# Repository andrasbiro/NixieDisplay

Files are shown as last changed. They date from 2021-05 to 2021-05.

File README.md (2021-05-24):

# Nixie Display

This is my modular nixie display/clock.

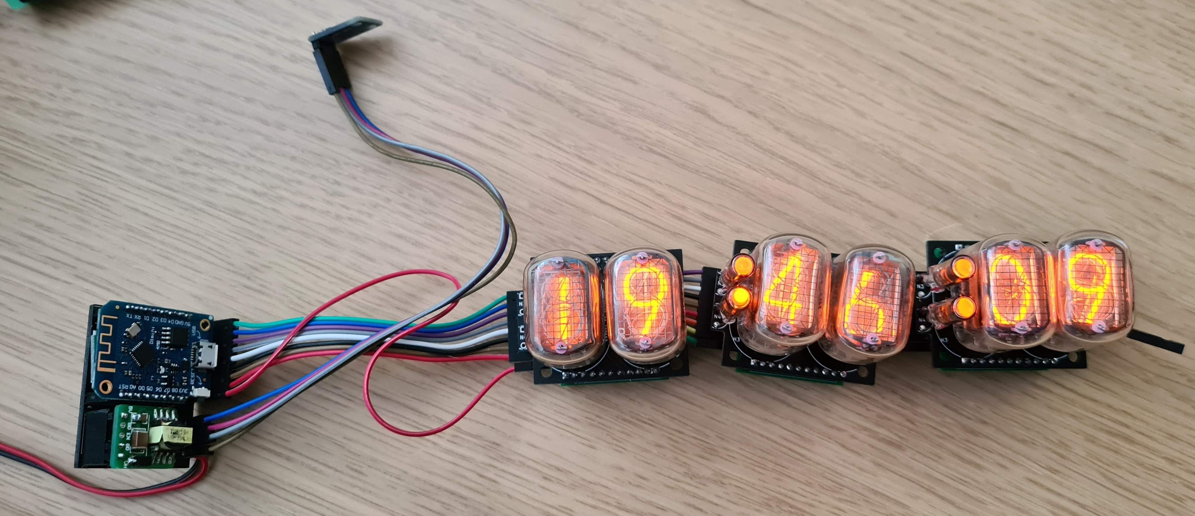
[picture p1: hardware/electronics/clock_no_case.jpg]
Bare clock before case design


It is designed around modules. Each module has:

- 2 nixie tube (with decimal point)
- preceiding colon
- shift register based cathode driver circuit
- any number of modules can be cascaded together

With my boards, the cathode drivers are sandwitched behind the main boards,

The control is based around a Wemos D1 mini and a small 170V power supply. It can also dim the tubes via PWM controlled optogate switching off the high voltage from the tubes.

The recommended input voltage is between 7.5V and 12V.

## Hardware

The PCB design is the most problematic part of the project. I'm proud of the small outline of the NixieBoards, but other than that, they are full with problems. For more details see [its own readme](./hardware/electronics/README.md).

3d printed case coming soon.

## Firmware

The firmware is written in platformIO.

### NixieLib

The nixie driver is written in its own library, what I called NixieLib, and is fully documented in its header file. It supports the following input formats:

- 2 digit number + 4 boolean for the 4 dots (decimal and colon) for each module
- Integer, right adjusted across all modules
- Fixed point number (float input, number of decimals in another input)

### Clock application

The clock gets the current time from NTP, converts it to local time (CET/CEST, modify the winter/summer variables for your timezone) and displays ont the tubes.

It also has OTA enabled and telnet based debugging.

## Future developement

These are the modifications I plan:

- 3d printed case
- simplify NTP/timezone, use ESP's time.h instead of libs
- MQTT support, so it can display anything from my home assistant
- BH1750fvi based dimming
- second display, using Z570M tubes

Otherwise, grab it and modify it to your heart's content, but I probably won't. Pull requests are welcome!

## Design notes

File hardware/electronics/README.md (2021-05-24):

# PCBs for nixie modules

These are the PCBs for the modular nixie display I designed, *but note that they
have many problems*. I'm a firmware engineer and I hate working on PCBs, and
even though these have many problems (and I autorouted most of them, which seems
sacrilege in hw design), it reached the point where it is good enough for me.

Pull requests are welcome.

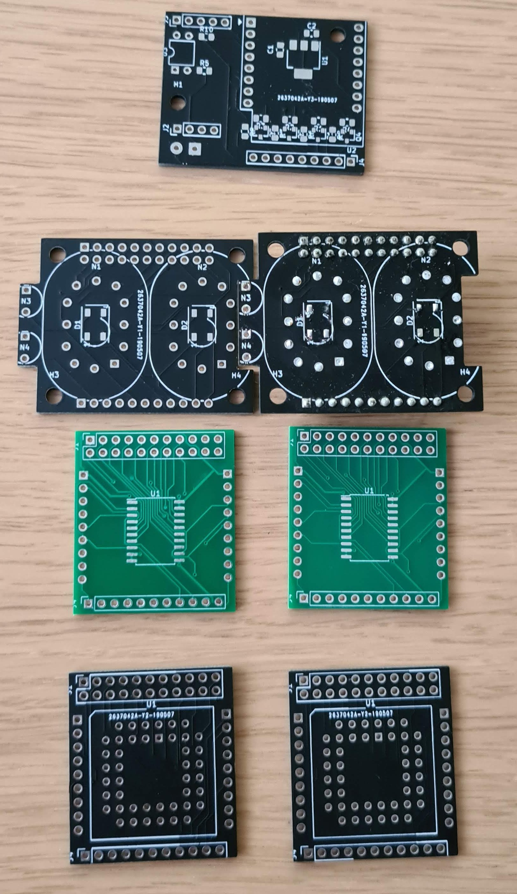
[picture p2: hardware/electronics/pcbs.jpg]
Bare PCBs


## The Nixie board

The Nixie board is designed around IN-12B nixies with INS-1 neon bulbs as colon.
When the colon is not populated, the pads of it can be hidden in the preceding
board. Therefor, the board can be used both as clock displays with a colon and
numerical displays.

It will likely work with thin legged standing style tubes too (like the GDR,
like Z570M).

This board also has 4 M3 mounting holes, in each corner (on a 36.5x29mm
rectangle)

The anode resistors should be tuned for the tubes and anode voltage, here's what
I used for IN-12B / INS-1 at 170V power supply:

- R1/R3: 12kOhm (main anode resistor)
- R2/R4: 91kOhm (additional resistor on the decimal point's cathode)
- R5/R6: 240kOhm (INS-1 anode resistor)

### Known issues

- The board includes a WS2812B ("neopixel") backlight for each tube but that
  never worked. However, I never really wanted to use it, just thought about
  maybe if it looks good, so I won't fix it.
- When used with TPIC6592 drivers, INS-1 needs an extra ~50V zener in series to
  allow it turn off. Since it is not socketed, it can be easily added.

## The Driver boards

The driver board fits under the nixie board and provides power/control to it. I
have two versions of it:

- Based on HV5122 (in socket)
- Based on TPIC6592 (smd)

I highliy recommend the one based on TPIC6592, as HV5122 does not have a true
latch (only output enable) and way more expensive.

Both design has footprint for filter caps, but I never used it on the TPIC
design.

The module connecting pin headers are ~15mm from each other when the nixie board
is used without colon, but I ended up using wires on one side and 90 degree pin
headers on the other. The excess wire can be tugged away between the boards.

### Known issues

- The 15mm distance was designed for pin headers measured for 14mm distance, but
  what I got in the end was much closer
- The HV5122 board is not very well tested. It was an earlier iteration of the
  design, but with a few hw errors, I managed to blew my chips, and I don't
  intend to order new ones.

## The Control board

**The control board has the most issues, and I strongly recommend against
manufacturing it before fixing it. However, I did fix it with ugly hacks, so I
won't bother paying for another run. I put it here for archiving only.**

The control board is designed around a Wemos D1 mini (or clone) and a
cheap/small 170V power supply, both readily available from aliexpress and
similar sites. It also has a pin header for I2C, where I have a bh1750fvi light
sensor panel connected for dimming.

### Known issues

- I missed routing the 12V input to anything - fixable with a jumper wire
- AMS1117 was a bad decision for running the Wemos, and every other 5V device. I
  currently have a 3 pin DCDC board wired to its pads
- I used an optogate for dimming (via PWM) the high voltage. My driver board has
  a shutdown pin that would have probably work just as good
- The level shifters are configured for 12V (HV5122), and needs cutting a
  trace/adding a jumper wire to set it for 5V, needed for the TPIC drivers
- The power input needs bigger holes on the PCB to be able to use with proper
  wire gauge.

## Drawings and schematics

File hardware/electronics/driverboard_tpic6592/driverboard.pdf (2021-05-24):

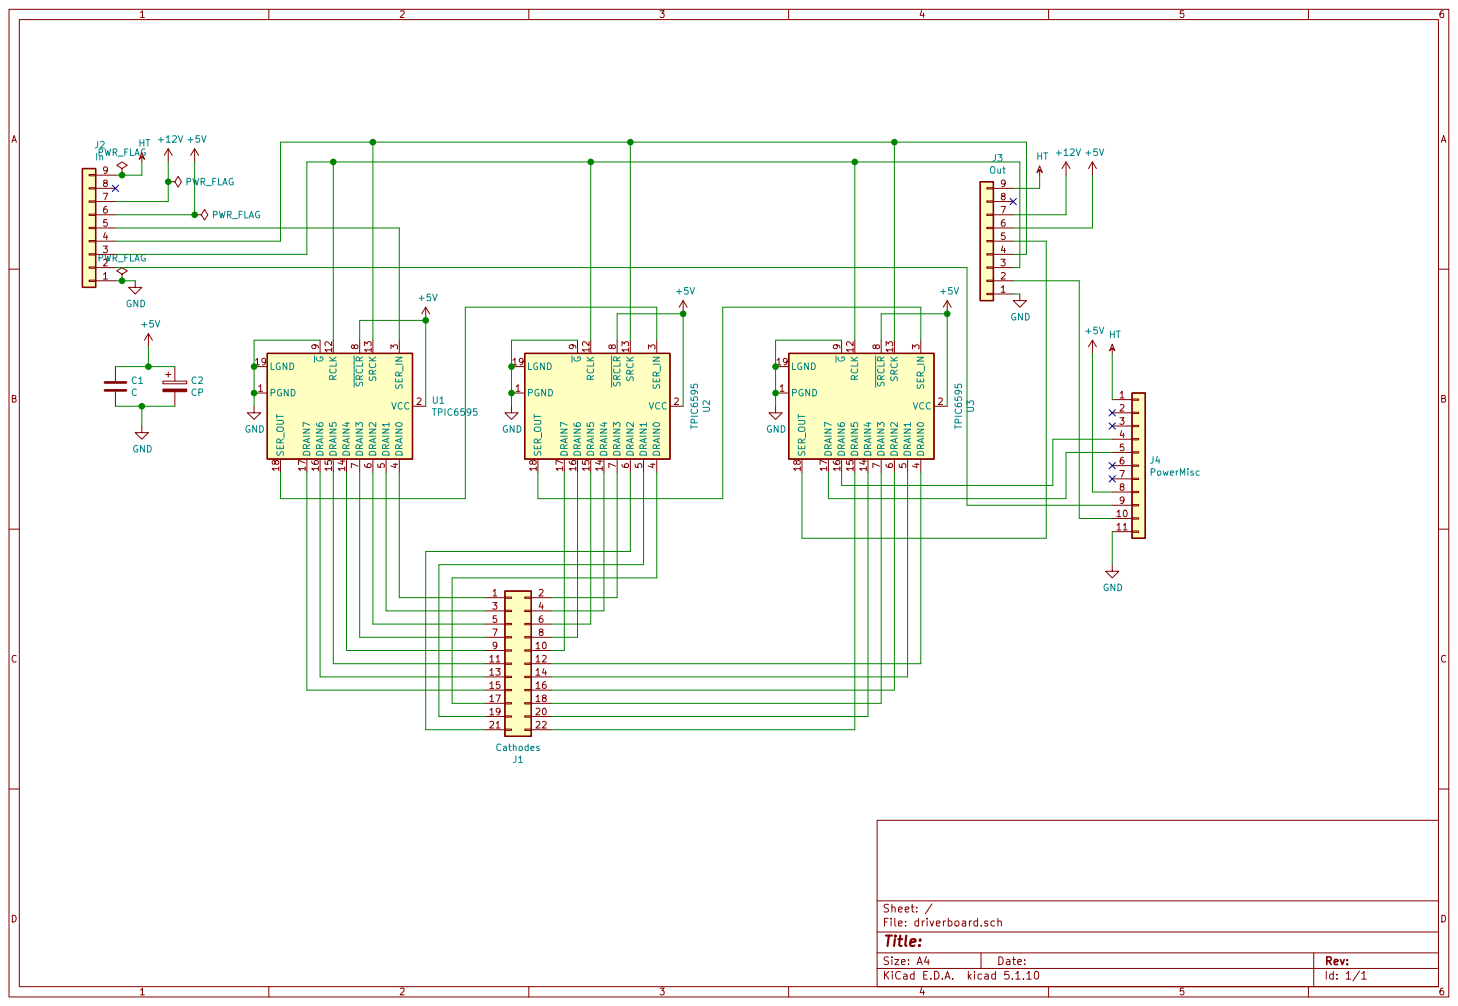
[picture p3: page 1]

Id: 1/1 Title: File: driverboard.sch Sheet: / GND

9 | 10
11 | 12
13 | 14
15 | 16
17 | 18

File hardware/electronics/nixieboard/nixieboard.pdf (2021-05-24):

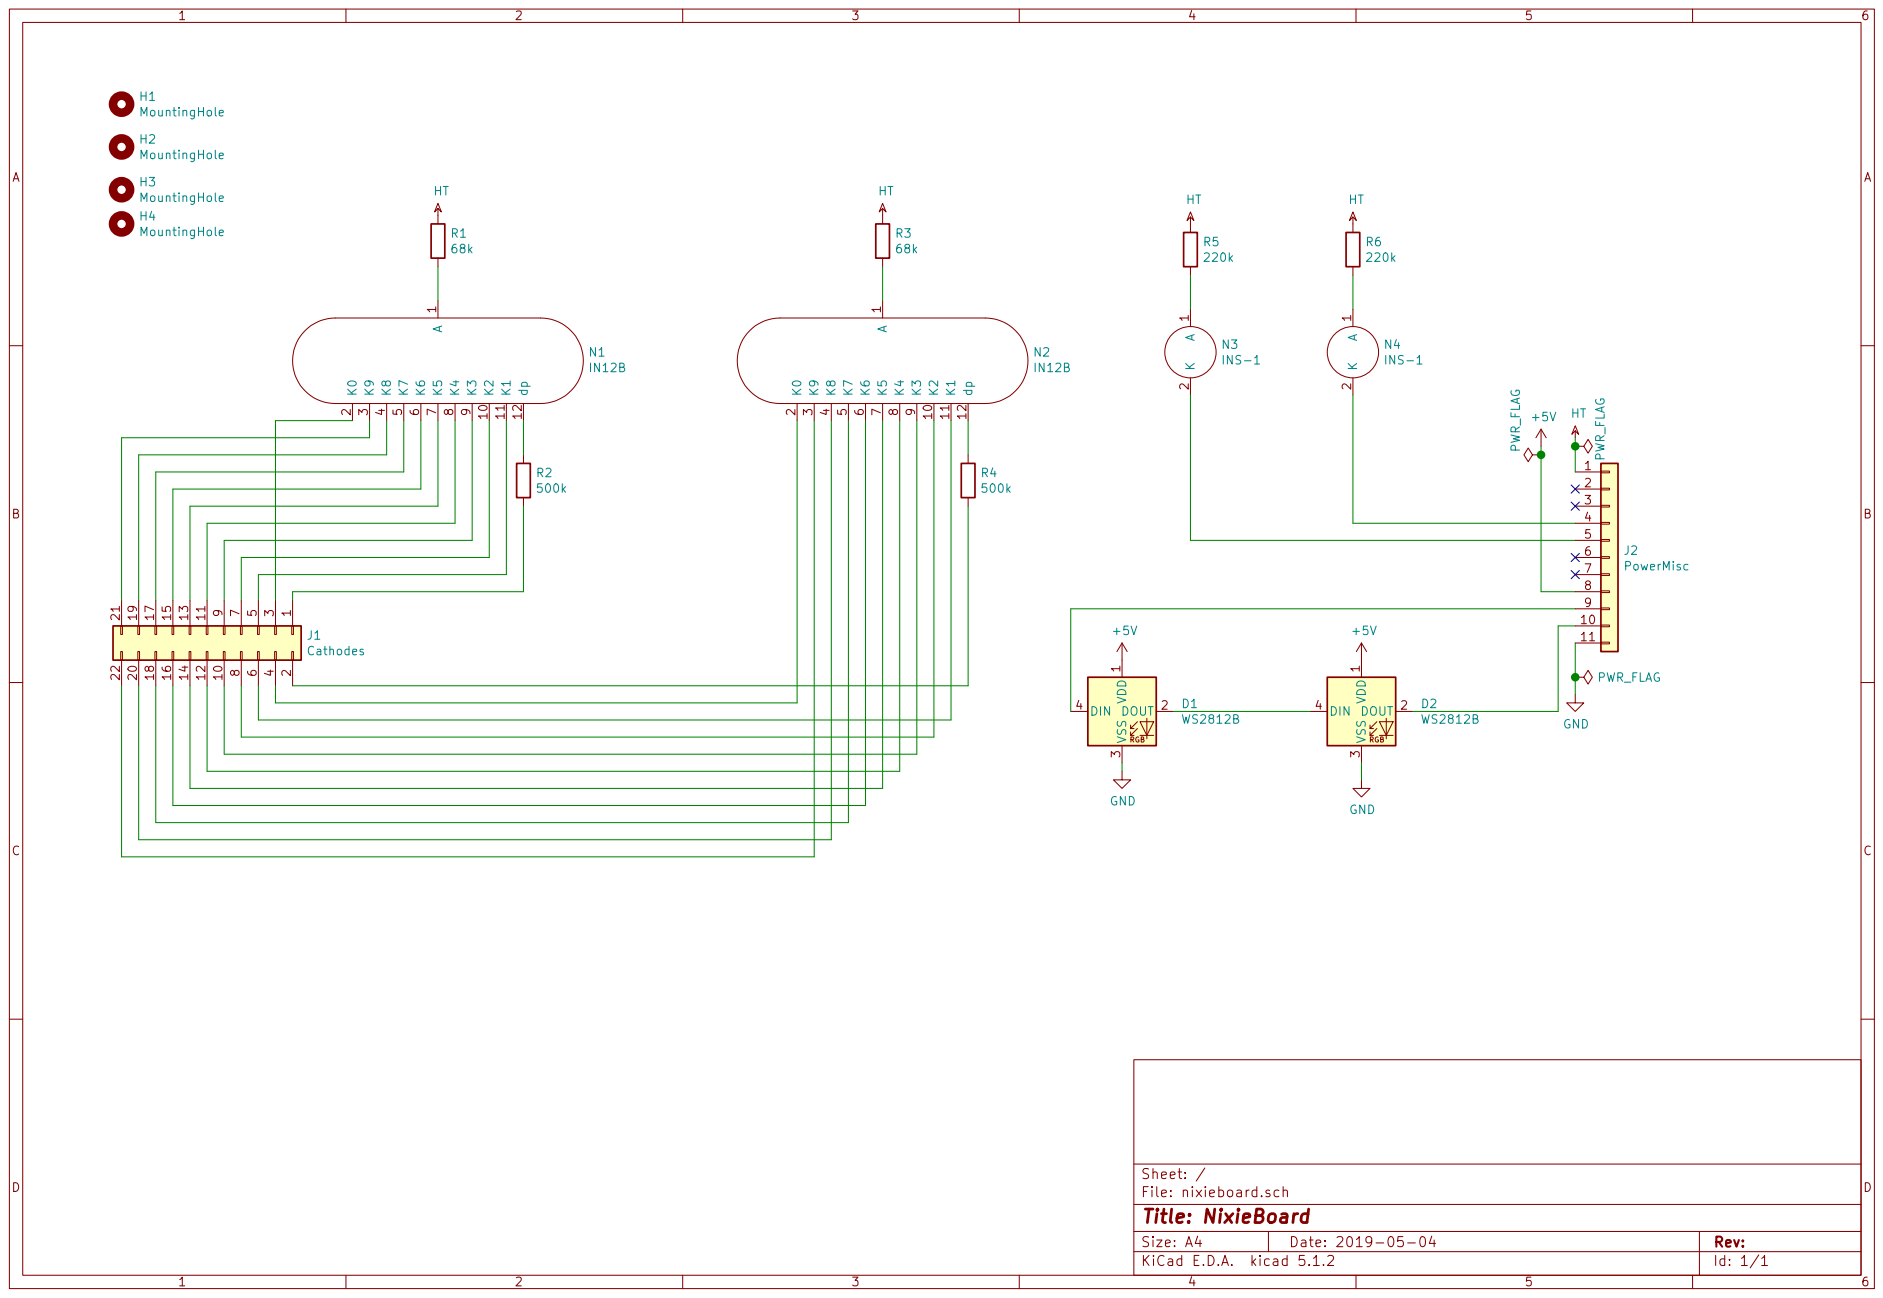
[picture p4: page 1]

3 DIN 4 D1WS2812B HT HT GND GND

File: nixieboard.sch Sheet: /
Id: 1/1 Title: NixieBoard

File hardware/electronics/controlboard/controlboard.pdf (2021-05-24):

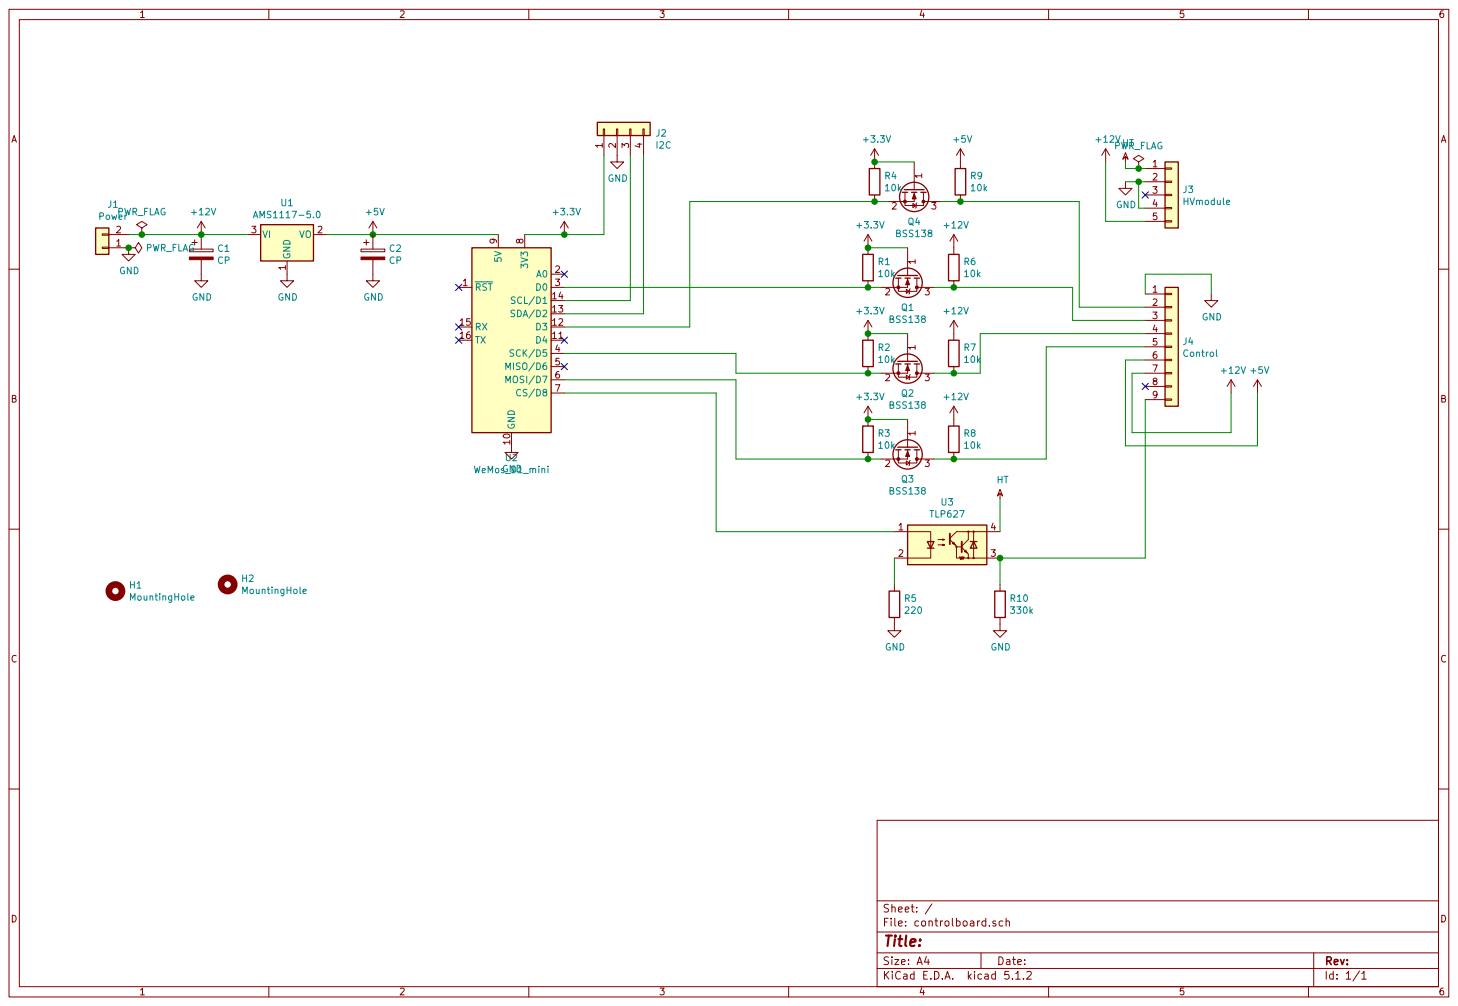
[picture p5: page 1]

Id: 1/1 Title: File: controlboard.sch Sheet: /

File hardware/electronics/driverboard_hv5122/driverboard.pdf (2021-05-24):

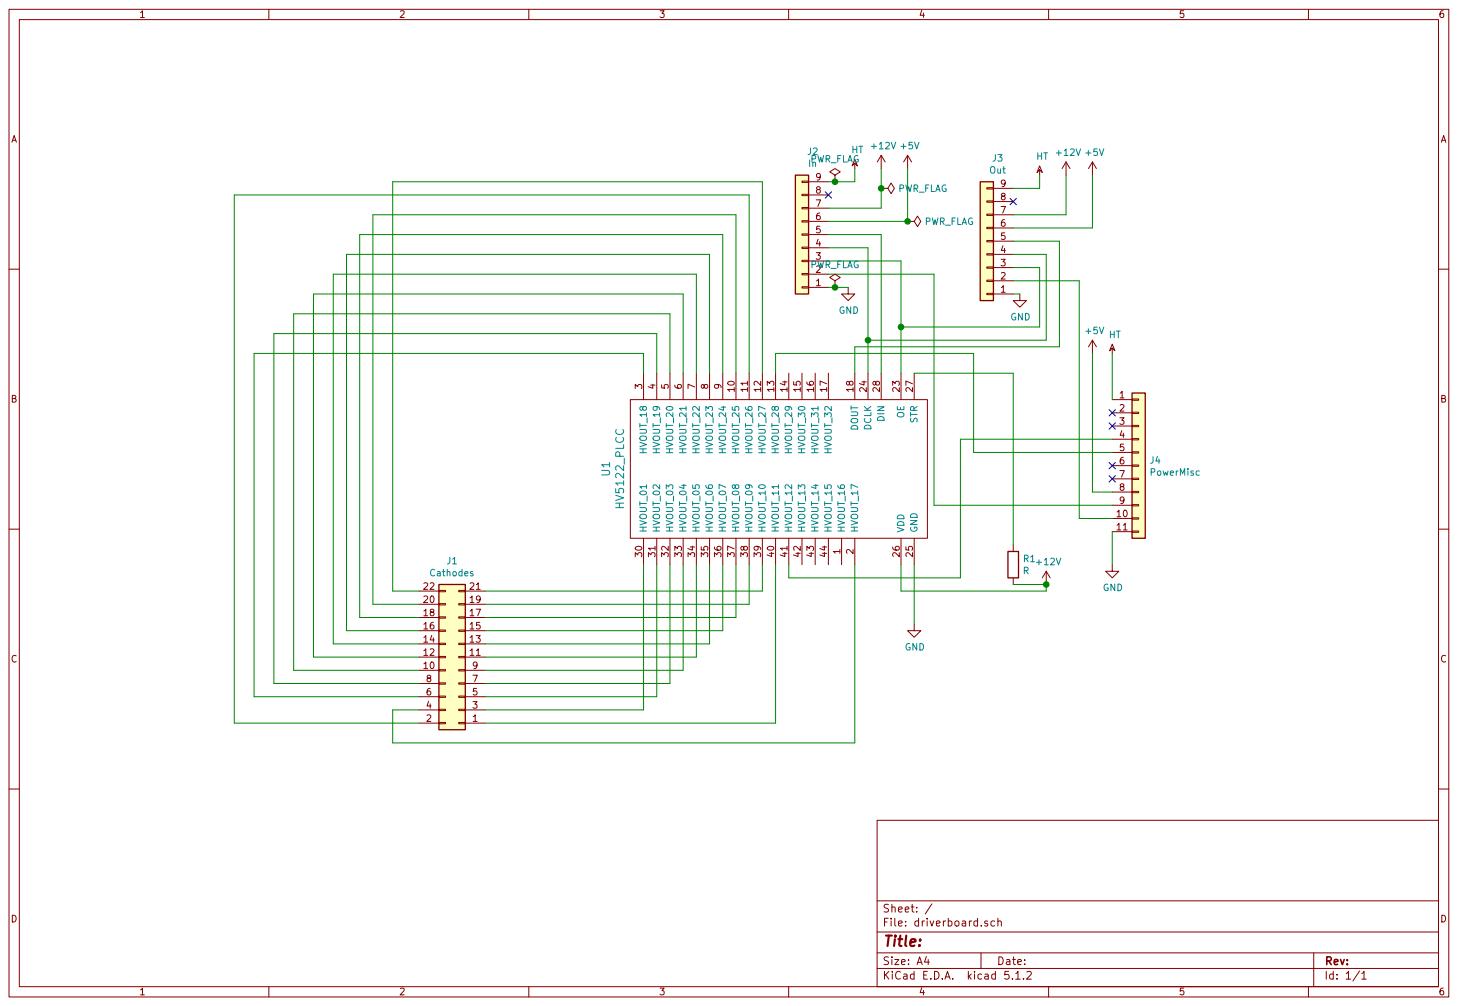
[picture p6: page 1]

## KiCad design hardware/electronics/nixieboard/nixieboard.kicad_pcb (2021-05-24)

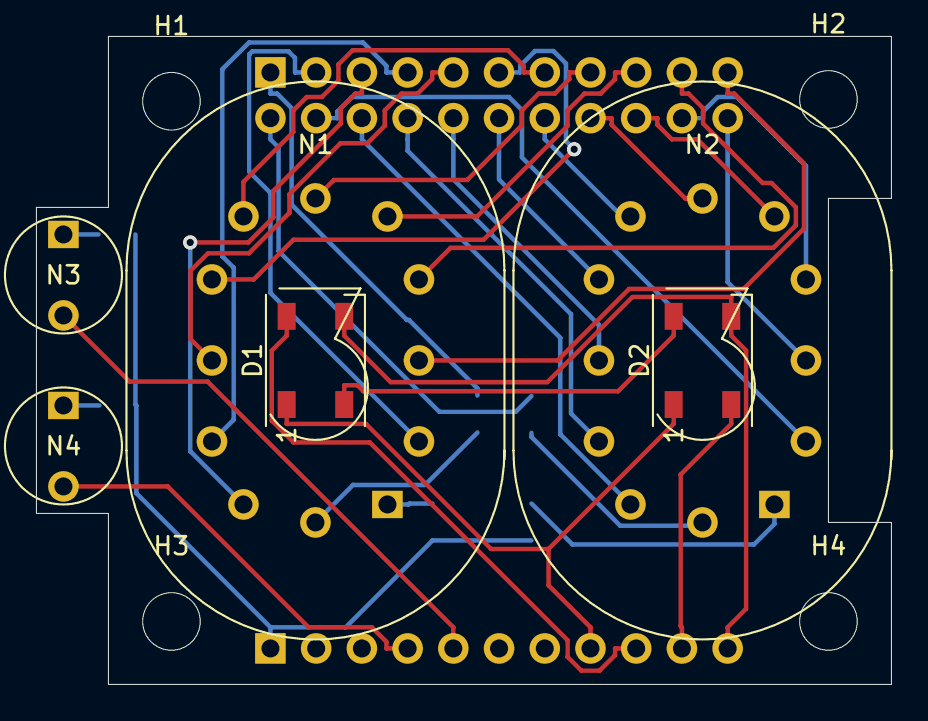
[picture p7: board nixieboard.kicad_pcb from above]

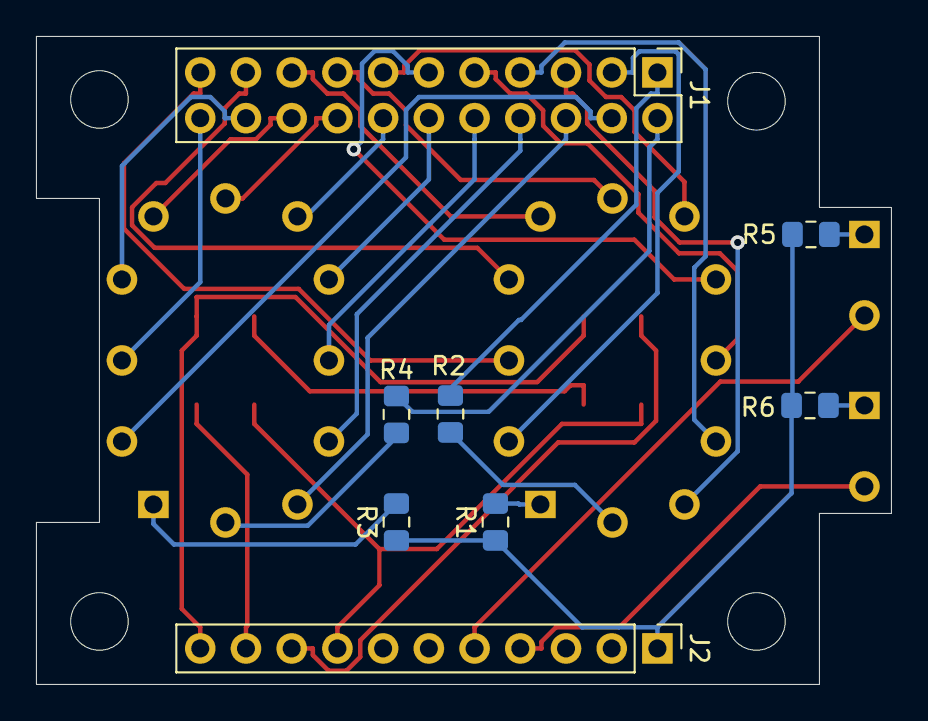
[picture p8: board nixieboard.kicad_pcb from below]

Board: 2 copper layers, 47.5 x 36.0 mm, 18 parts (8 on the bottom side), 36 nets.

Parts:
D1, D2: WS2812B; LED_WS2812B_PLCC4_5.0x5.0mm_P3.2mm
H1, H2, H3, H4: MountingHole; MountingHole_3.2mm_M3
J1: Cathodes; PinHeader_2x11_P2.54mm_Vertical
J2: PowerMisc; PinHeader_1x11_P2.54mm_Vertical
N1, N2: IN12B; in12b_pinsocket
N3, N4: INS-1; ins-1
R1, R3: 68k; R_0805_2012Metric_Pad1.15x1.40mm_HandSolder
R2, R4: 500k; R_0805_2012Metric_Pad1.15x1.40mm_HandSolder
R5, R6: 220k; R_0805_2012Metric_Pad1.15x1.40mm_HandSolder

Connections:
+5V: D1.1, D2.1, J2.8
GND: D1.3, D2.3, J2.11
HT: J2.1, R1.1, R3.1, R5.1, R6.1
unnamed: D1.2, D2.4
unnamed: D1.4, J2.9
unnamed: D2.2, J2.10
unnamed: J1.1, R2.2
unnamed: J1.2, R4.2
unnamed: J1.3, N1.2
unnamed: J1.4, N2.2
unnamed: J1.5, N1.11
unnamed: J1.6, N2.11
unnamed: J1.7, N1.10
unnamed: J1.8, N2.10
unnamed: J1.9, N1.9
unnamed: J1.10, N2.9
unnamed: J1.11, N1.8
unnamed: J1.12, N2.8
unnamed: J1.13, N1.7
unnamed: J1.14, N2.7
unnamed: J1.15, N1.6
unnamed: J1.16, N2.6
unnamed: J1.17, N1.5
unnamed: J1.18, N2.5
unnamed: J1.19, N1.4
unnamed: J1.20, N2.4
unnamed: J1.21, N1.3
unnamed: J1.22, N2.3
unnamed: J2.4, N4.2
unnamed: J2.5, N3.2
unnamed: N1.1, R1.2
unnamed: N1.12, R2.1
unnamed: N2.1, R3.2
unnamed: N2.12, R4.1
unnamed: N3.1, R5.2
unnamed: N4.1, R6.2

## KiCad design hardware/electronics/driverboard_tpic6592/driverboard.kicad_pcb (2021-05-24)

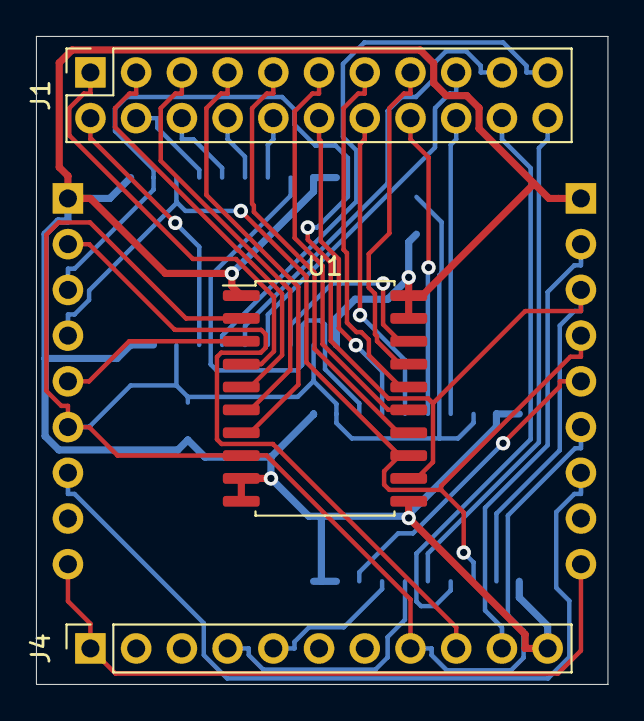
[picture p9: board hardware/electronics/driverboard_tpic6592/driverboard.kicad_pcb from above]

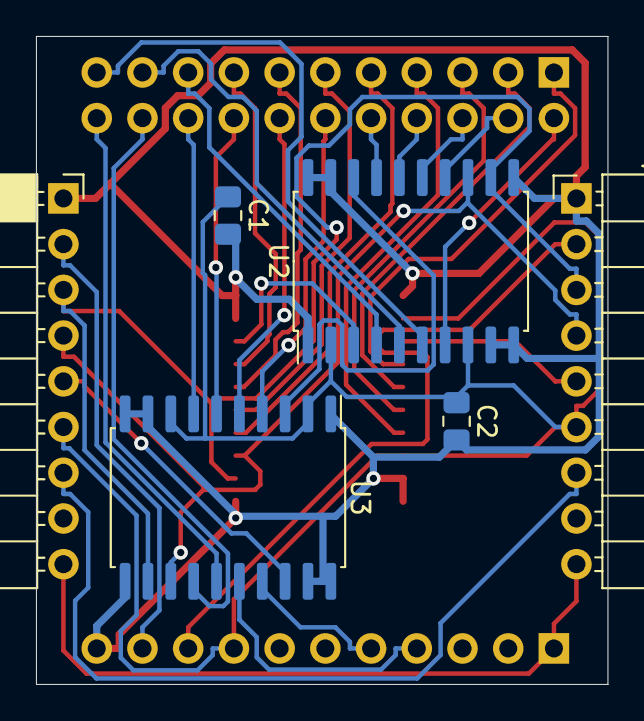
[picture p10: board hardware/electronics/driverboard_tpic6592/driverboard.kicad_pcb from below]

Board: 2 copper layers, 31.8 x 36.0 mm, 9 parts (6 on the bottom side), 36 nets.

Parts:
C1: C; C_0805_2012Metric_Pad1.18x1.45mm_HandSolder
C2: CP; C_0805_2012Metric_Pad1.18x1.45mm_HandSolder
J1: Cathodes; PinSocket_2x11_P2.54mm_Vertical
J2: In; PinHeader_1x09_P2.54mm_Horizontal
J3: Out; PinSocket_1x09_P2.54mm_Horizontal
J4: PowerMisc; PinSocket_1x11_P2.54mm_Vertical
U1, U2, U3: TPIC6595; SOIC-20W_7.5x12.8mm_P1.27mm

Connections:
+5V: C1.1, C2.1, J2.6, J3.6, J4.8, U1.2, U1.8, U2.2, U2.8, U3.2, U3.8
+12V: J2.7, J3.7
GND: C1.2, C2.2, J2.1, J3.1, J4.11, U1.1, U1.9, U1.10, U1.11, U1.19, U1.20, U2.1, U2.9, U2.10, U2.11, U2.19, U2.20, U3.1, U3.9, U3.10, U3.11, U3.19, U3.20
HT: J2.9, J3.9, J4.1
unnamed: J1.1, U1.4
unnamed: J1.2, U2.7
unnamed: J1.3, U1.5
unnamed: J1.4, U2.14
unnamed: J1.5, U1.6
unnamed: J1.6, U2.15
unnamed: J1.7, U1.7
unnamed: J1.8, U2.16
unnamed: J1.9, U1.14
unnamed: J1.10, U2.17
unnamed: J1.11, U1.15
unnamed: J1.12, U3.4
unnamed: J1.13, U1.16
unnamed: J1.14, U3.5
unnamed: J1.15, U1.17
unnamed: J1.16, U3.6
unnamed: J1.17, U2.4
unnamed: J1.18, U3.7
unnamed: J1.19, U2.5
unnamed: J1.20, U3.14
unnamed: J1.21, U2.6
unnamed: J1.22, U3.15
unnamed: J2.2, J4.9
unnamed: J2.3, J3.3, U1.12, U2.12, U3.12
unnamed: J2.4, J3.4, U1.13, U2.13, U3.13
unnamed: J2.5, U1.3
unnamed: J3.2, J4.10
unnamed: J3.5, U3.18
unnamed: J4.4, U3.16
unnamed: J4.5, U3.17
unnamed: U1.18, U2.3
unnamed: U2.18, U3.3

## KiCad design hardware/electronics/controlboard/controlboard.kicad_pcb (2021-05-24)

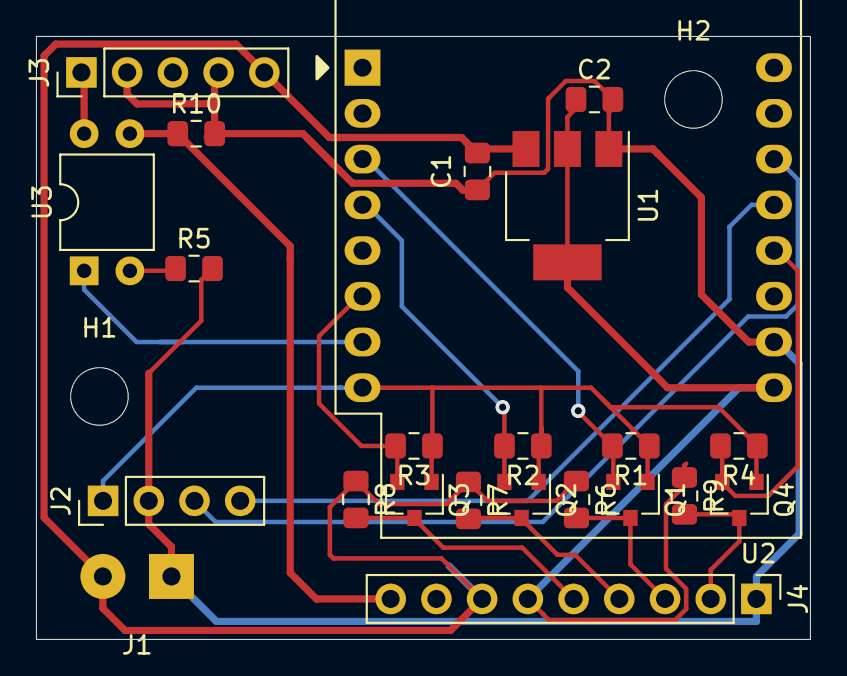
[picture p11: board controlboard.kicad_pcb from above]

Board: 2 copper layers, 43.0 x 33.5 mm, 25 parts (0 on the bottom side), 18 nets.

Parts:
C1, C2: CP; C_0805_2012Metric_Pad1.15x1.40mm_HandSolder
H1, H2: MountingHole; MountingHole_3.2mm_M3_DIN965
J1: Power; SolderWirePad_1x02_P3.81mm_Drill1mm
J2: I2C; PinHeader_1x04_P2.54mm_Vertical
J3: HVmodule; PinHeader_1x05_P2.54mm_Vertical
J4: Control; PinHeader_1x09_P2.54mm_Vertical
Q1, Q2, Q3, Q4: BSS138; SOT-23
R1, R2, R3, R4, R6, R7, R8, R9: 10k; R_0805_2012Metric_Pad1.15x1.40mm_HandSolder
R5: 220; R_0805_2012Metric_Pad1.15x1.40mm_HandSolder
R10: 330k; R_0805_2012Metric_Pad1.15x1.40mm_HandSolder
U1: AMS1117-5.0; SOT-223-3_TabPin2
U2: WeMos_D1_mini; WEMOS_D1_mini_light
U3: TLP627; DIP-4_W7.62mm

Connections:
+3V3: J2.1, Q1.1, Q2.1, Q3.1, Q4.1, R1.1, R2.1, R3.1, R4.1, U2.8
+5V: C2.1, J4.6, R9.1, U1.2, U2.9
+12V: C1.1, J1.2, J3.5, J4.7, R6.1, R7.1, R8.1, U1.3
GND: C1.2, C2.2, J1.1, J2.2, J3.2, J3.4, J4.1, R5.2, R10.2, U1.1, U2.10
HT: J3.1, U3.4
unnamed: J2.3, U2.14
unnamed: J2.4, U2.13
unnamed: J4.2, Q4.3, R9.2
unnamed: J4.3, Q1.3, R6.2
unnamed: J4.4, Q2.3, R7.2
unnamed: J4.5, Q3.3, R8.2
unnamed: J4.9, R10.1, U3.3
unnamed: Q1.2, R1.2, U2.3
unnamed: Q2.2, R2.2, U2.4
unnamed: Q3.2, R3.2, U2.6
unnamed: Q4.2, R4.2, U2.12
unnamed: R5.1, U3.2
unnamed: U2.7, U3.1

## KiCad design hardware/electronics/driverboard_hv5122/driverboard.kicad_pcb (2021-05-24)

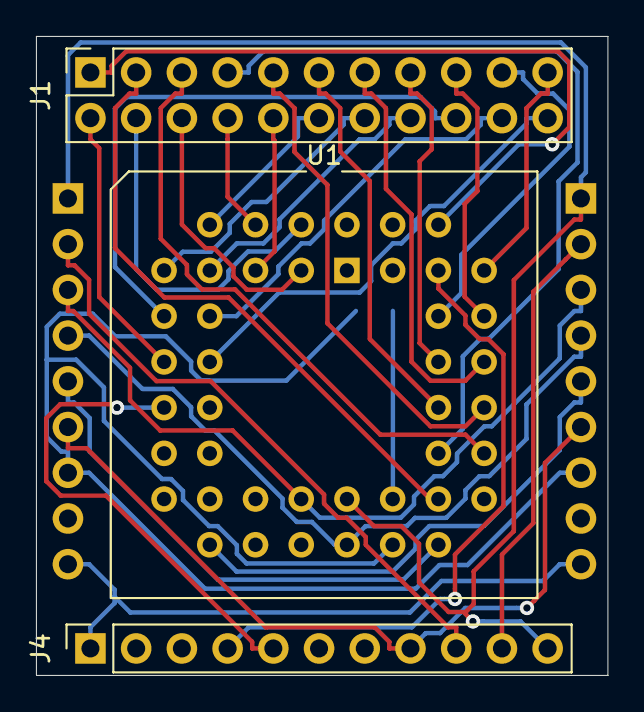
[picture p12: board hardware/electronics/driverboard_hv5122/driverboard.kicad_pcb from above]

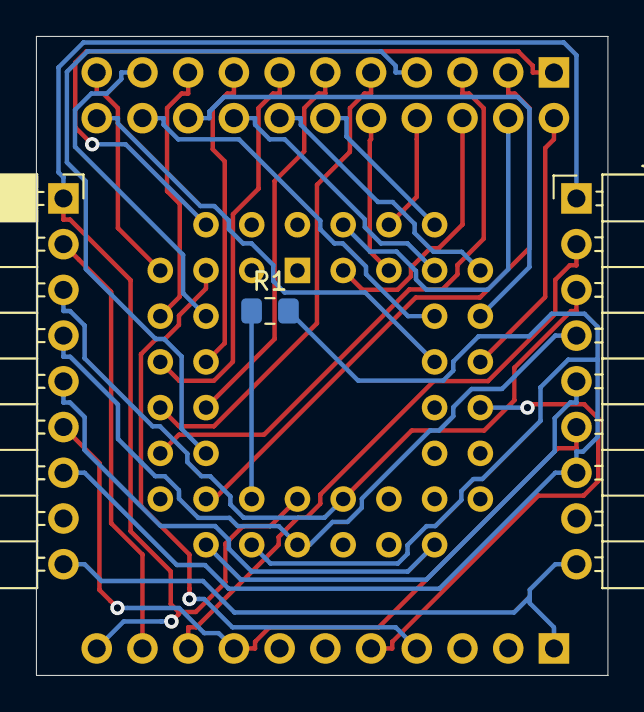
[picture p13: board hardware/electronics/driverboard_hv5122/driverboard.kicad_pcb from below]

Board: 2 copper layers, 31.8 x 35.5 mm, 6 parts (3 on the bottom side), 35 nets.

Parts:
J1: Cathodes; PinSocket_2x11_P2.54mm_Vertical
J2: In; PinHeader_1x09_P2.54mm_Horizontal
J3: Out; PinSocket_1x09_P2.54mm_Horizontal
J4: PowerMisc; PinSocket_1x11_P2.54mm_Vertical
R1: R; R_0805_2012Metric_Pad1.15x1.40mm_HandSolder
U1: HV5122_PLCC; PLCC-44_THT-Socket

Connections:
+5V: J2.6, J3.6, J4.8
+12V: J2.7, J3.7, R1.2, U1.26
GND: J2.1, J3.1, J4.11, U1.25
HT: J2.9, J3.9, J4.1
unnamed: J1.1, U1.40
unnamed: J1.2, U1.11
unnamed: J1.3, U1.30
unnamed: J1.4, U1.2
unnamed: J1.5, U1.31
unnamed: J1.6, U1.3
unnamed: J1.7, U1.32
unnamed: J1.8, U1.4
unnamed: J1.9, U1.33
unnamed: J1.10, U1.5
unnamed: J1.11, U1.34
unnamed: J1.12, U1.6
unnamed: J1.13, U1.35
unnamed: J1.14, U1.7
unnamed: J1.15, U1.36
unnamed: J1.16, U1.8
unnamed: J1.17, U1.37
unnamed: J1.18, U1.9
unnamed: J1.19, U1.38
unnamed: J1.20, U1.10
unnamed: J1.21, U1.39
unnamed: J1.22, U1.12
unnamed: J2.2, J4.9
unnamed: J2.3, J3.3, U1.23
unnamed: J2.4, J3.4, U1.24
unnamed: J2.5, U1.28
unnamed: J3.2, J4.10
unnamed: J3.5, U1.18
unnamed: J4.4, U1.41
unnamed: J4.5, U1.13
unnamed: R1.1, U1.27

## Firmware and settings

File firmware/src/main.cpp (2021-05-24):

#include <ESP8266WiFi.h>

#include <ESP8266WebServer.h>
#include <WiFiManager.h>
#include <ArduinoOTA.h>

#include <NTPClient.h>
#include <WiFiUdp.h>
#include <TimeLib.h>
#include <Timezone.h>

#include <Adafruit_NeoPixel.h>

#include "NixieLib.h"

#define GPIO_LATCH D0
#define GPIO_PWM D8

#define GPIO_MOSI D7
#define GPIO_SCK D5

#define GPIO_NEOPIXEL D3

//D1 SCL, D2 SDA

#define NAME "Nixie ESP Clock"

WiFiUDP ntpUDP;
NTPClient timeClient(ntpUDP);
WiFiManager wifiManager;

WiFiServer telnetServer(23);
WiFiClient debugClient;

Stream *debug = &Serial;

TimeChangeRule winter = {"CET", Last, Sun, Oct, 2, 60};    //UTC + 1 hours
TimeChangeRule summer = {"CEST", Last, Sun, Mar, 2, 120};     //UTC + 2 hours
Timezone timeZone(winter, summer);

#define NUMMODULES 3
NixieLib nixies = NixieLib(NUMMODULES, NIXIE_MODULE_TYPE_TPIC6592, GPIO_LATCH, GPIO_PWM, 0);

Adafruit_NeoPixel leds = Adafruit_NeoPixel(NUMMODULES*2, GPIO_NEOPIXEL, NEO_GRB + NEO_KHZ800);


void setup() {
  Serial.begin(115200);


  nixies.setBrightness(PWMRANGE); //5 is practical minimum

  //blank tubes, but light all the dots
  nixies.setNixieModule(0, 00, BLANKBOTHDIGITS, true, true, true, true);
  nixies.setNixieModule(1, 00, BLANKBOTHDIGITS, true, true, true, true);
  nixies.setNixieModule(2, 00, BLANKBOTHDIGITS, true, true, true, true);
  nixies.updateNixies();

  //The LEDs do not work, except sometimes the first one. So turn it off for uniformity
  leds.begin();
  leds.fill(0);
  leds.show();

  wifiManager.autoConnect("AutoConnectAP"); //TODO this is blocking. Add RTC and non-blocking config
  timeClient.begin();
  telnetServer.begin();
  telnetServer.setNoDelay(true);

  ArduinoOTA.setHostname ( NAME ) ;                  // Set the hostname
  ArduinoOTA.begin() ;




  Serial.println("booted");

}

uint32_t number;
float fnumber;

void secondLoop(){
  timeClient.update(); //this only updates if the interval set in timeClient is reached
  time_t local = timeZone.toLocal(timeClient.getEpochTime());


  // nixies.setNixies(number);
  // debug->printf("nixies set to %dL\n", number);
  // number = random(999999);

  // fnumber = 12.3;
  // nixies.setNixies(fnumber, 3, false);
  // debug->printf("nixies set to %f\n", fnumber);
  // fnumber = (float)rand()/(RAND_MAX/9999);

  // nixies.setNixies(" 11..34^5.6");

  nixies.setNixieModule(0, (uint8_t)second(local), SHOWALLZEROS, false, false, true, true);
  nixies.setNixieModule(1, (uint8_t)minute(local), SHOWALLZEROS, false, false, true, true);
  nixies.setNixieModule(2, (uint8_t)hour(local), SHOWLONEZERO, false, false, false, false);

  nixies.updateNixies();


  // debug->print("UTC: ");
  // debug->print(timeClient.getFormattedTime());
  // debug->println();
  // debug->print("Loc: ");
  // debug->print(hour(local));
  // debug->print(minute(local)<10 ? ":0" : ":");
  // debug->print(minute(local));
  // debug->print(second(local)<10 ? ":0" : ":");
  // debug->print(second(local));
  // debug->println();
}

uint32_t secondLoopLastRun = 0;

void telnetLoop(){
  if (telnetServer.hasClient()) {
    debugClient = telnetServer.available();
    Serial.println("New Telnet client");
    debugClient.flush();  // clear input buffer, else you get strange characters
    debug = &debugClient;
  }

  //drop data if available
  while(debugClient.available()) {
    debugClient.read();
  }

  if ( debug == &debugClient && !debugClient.connected() ){
    debug = &Serial;
    debugClient.stop();
    Serial.println("Telnet Client Stop");
  }
}

void loop() {
  ArduinoOTA.handle();
  telnetLoop();


  if ( millis () - secondLoopLastRun > 1000 ){
    secondLoopLastRun = millis();
    secondLoop();
  }
}
